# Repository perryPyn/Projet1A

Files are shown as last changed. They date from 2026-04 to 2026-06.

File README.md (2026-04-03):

Ce projet, réalisé dans le cadre du Semestre 6 à l'ENSEA (Année 2025-2026), consiste à développer un prototype de mesure de distance basé sur la technologie Time Of Flight (TOF). L'objectif est d'utiliser un capteur laser compact pour détecter des obstacles et commander une interface visuelle de retour.

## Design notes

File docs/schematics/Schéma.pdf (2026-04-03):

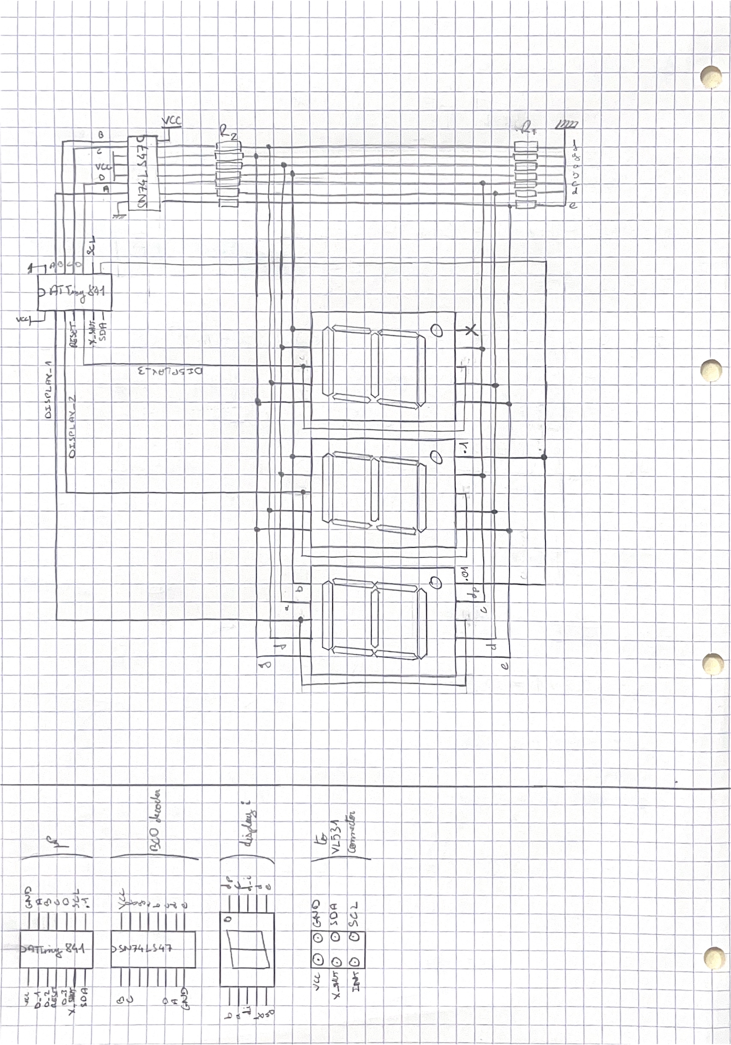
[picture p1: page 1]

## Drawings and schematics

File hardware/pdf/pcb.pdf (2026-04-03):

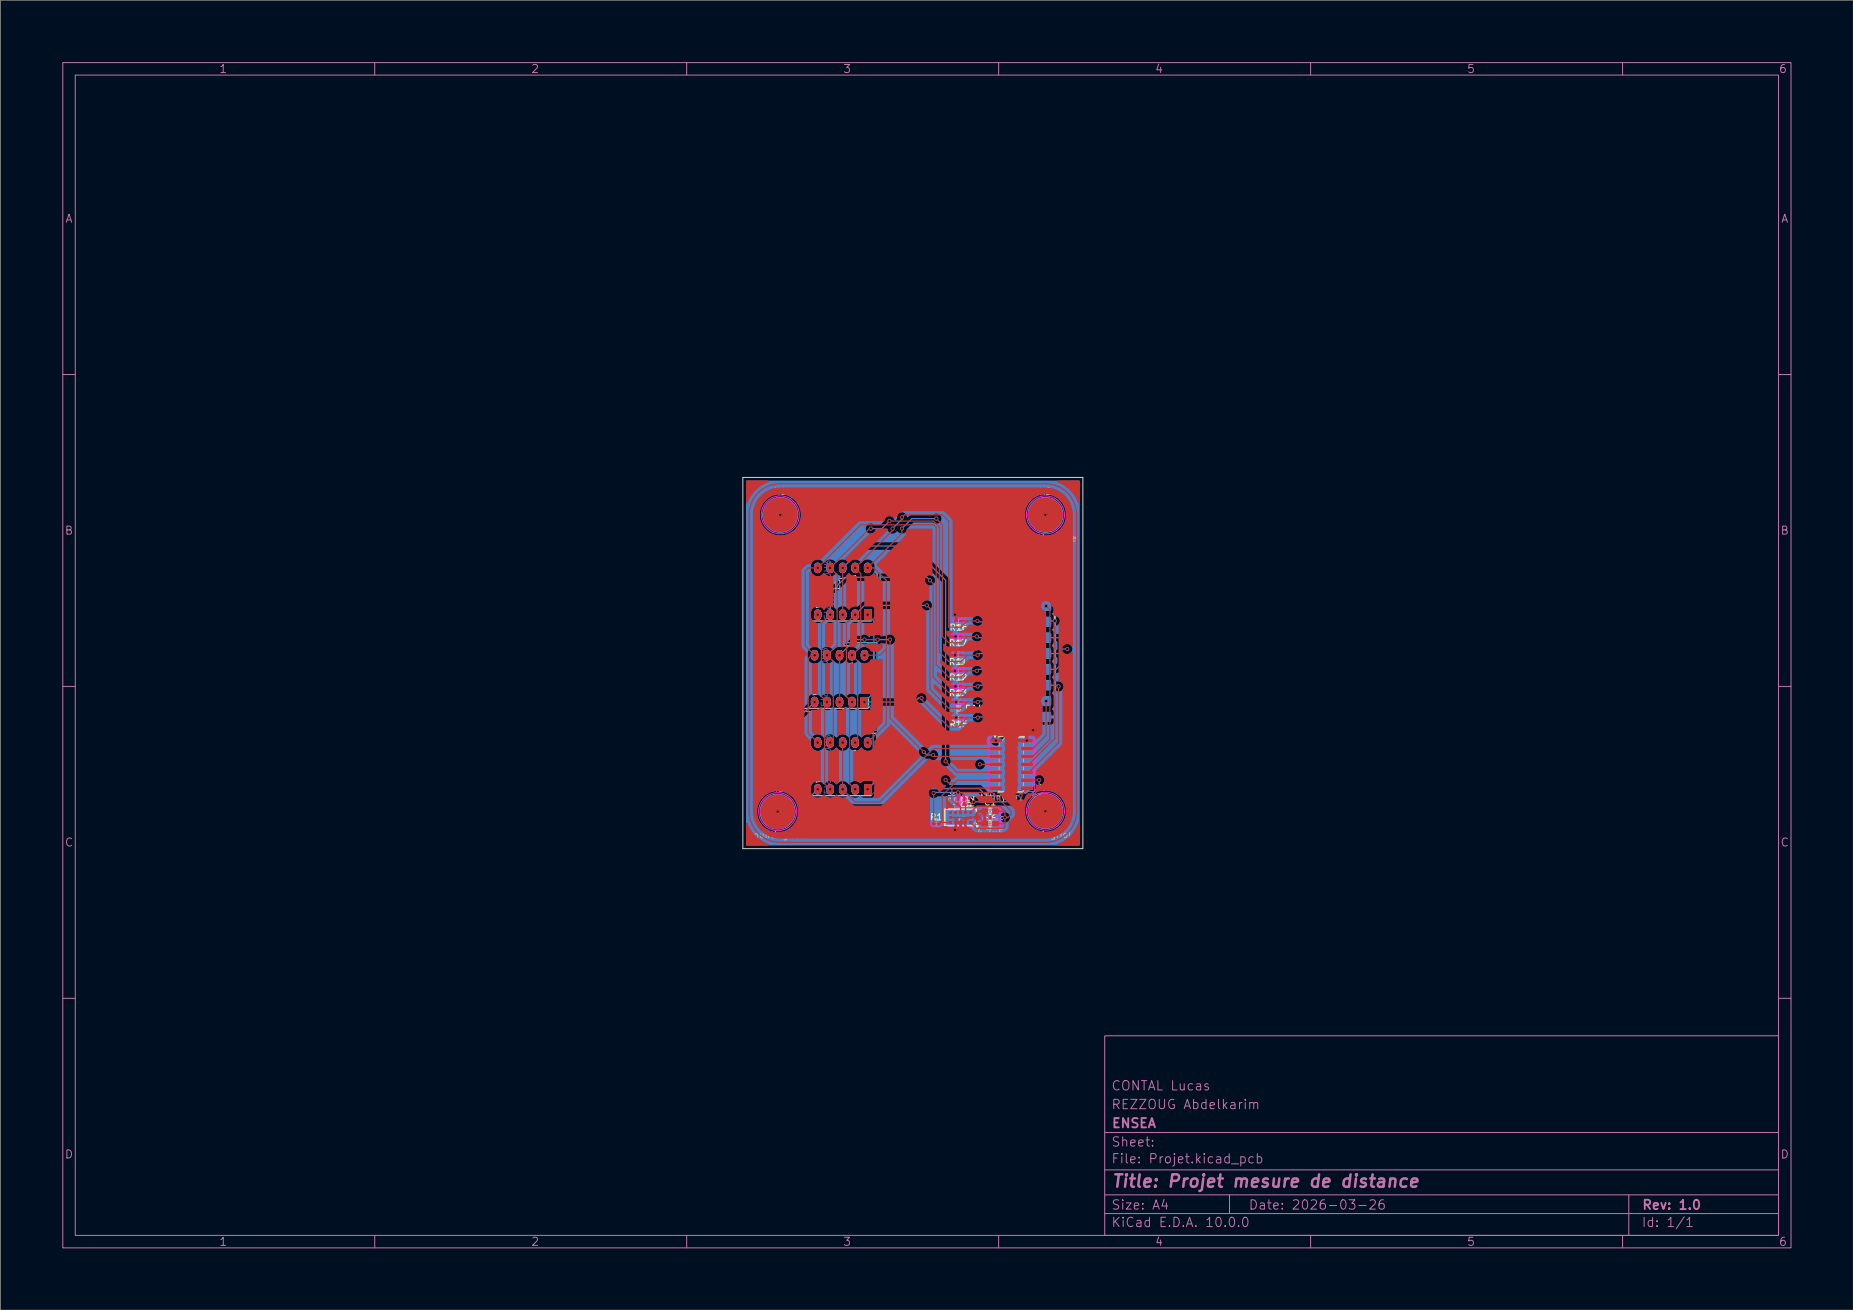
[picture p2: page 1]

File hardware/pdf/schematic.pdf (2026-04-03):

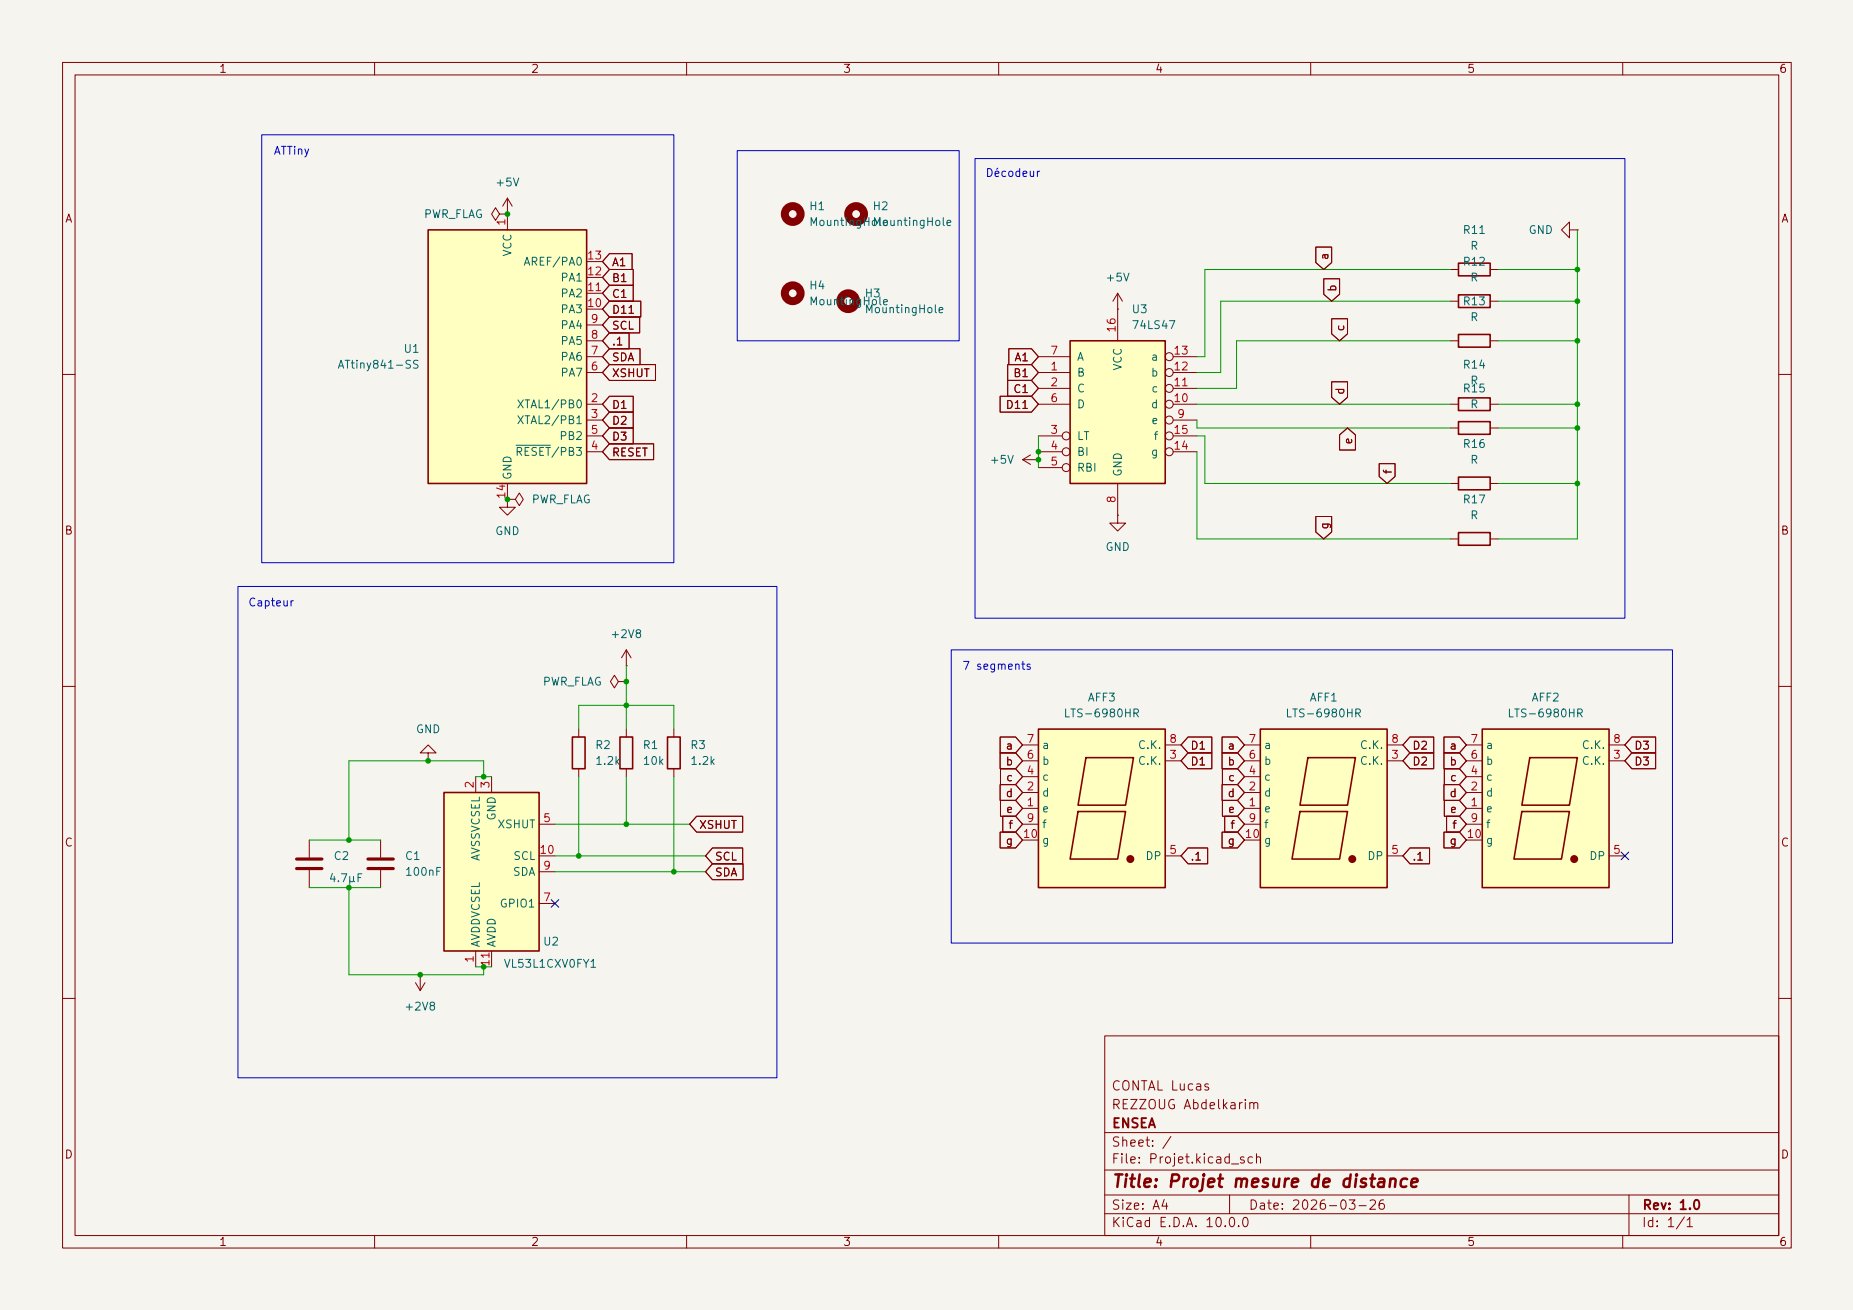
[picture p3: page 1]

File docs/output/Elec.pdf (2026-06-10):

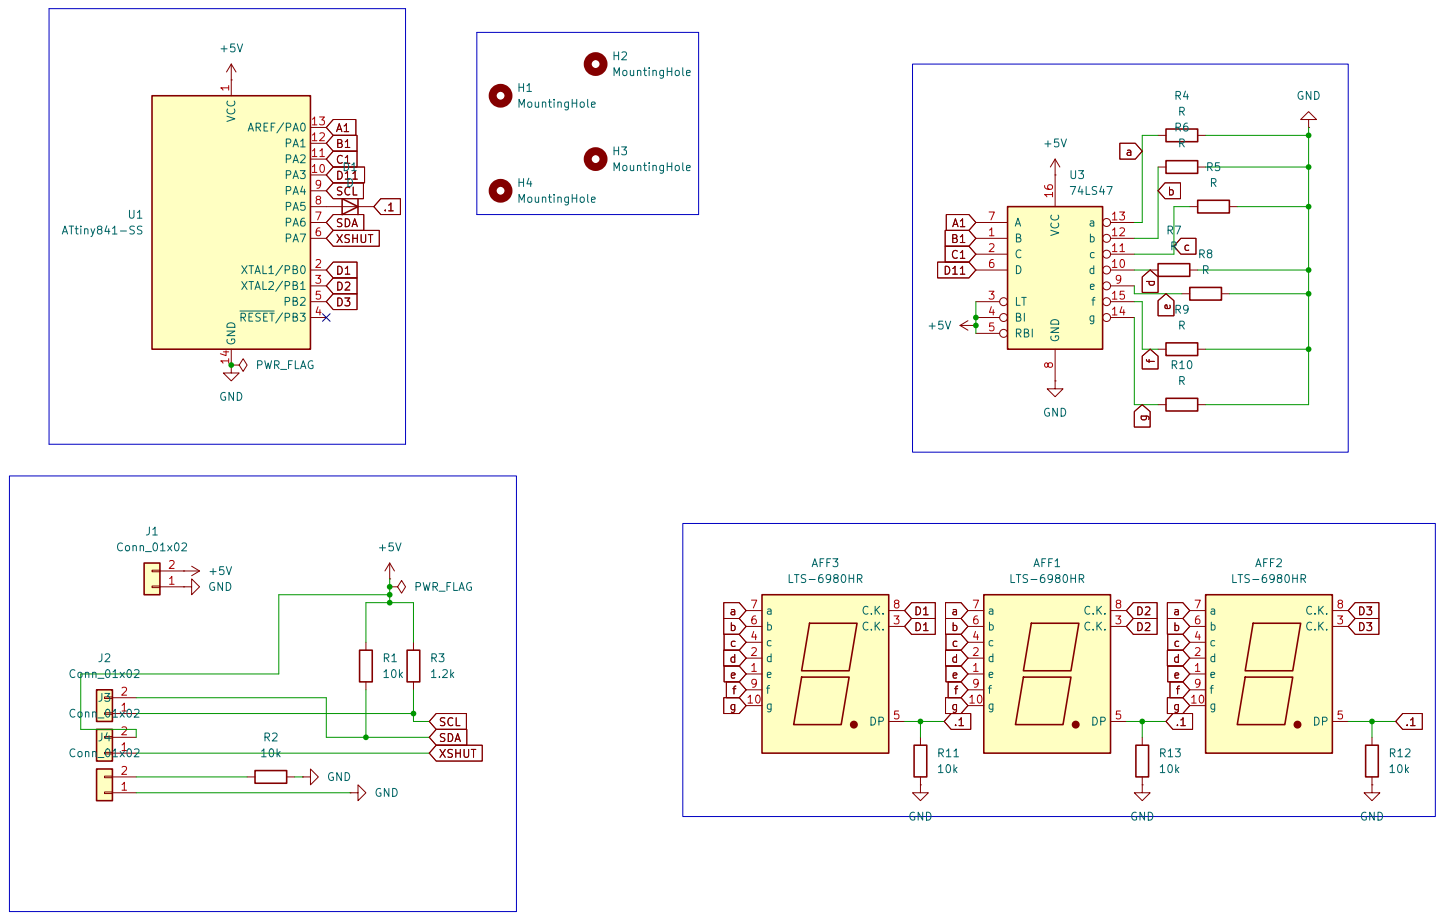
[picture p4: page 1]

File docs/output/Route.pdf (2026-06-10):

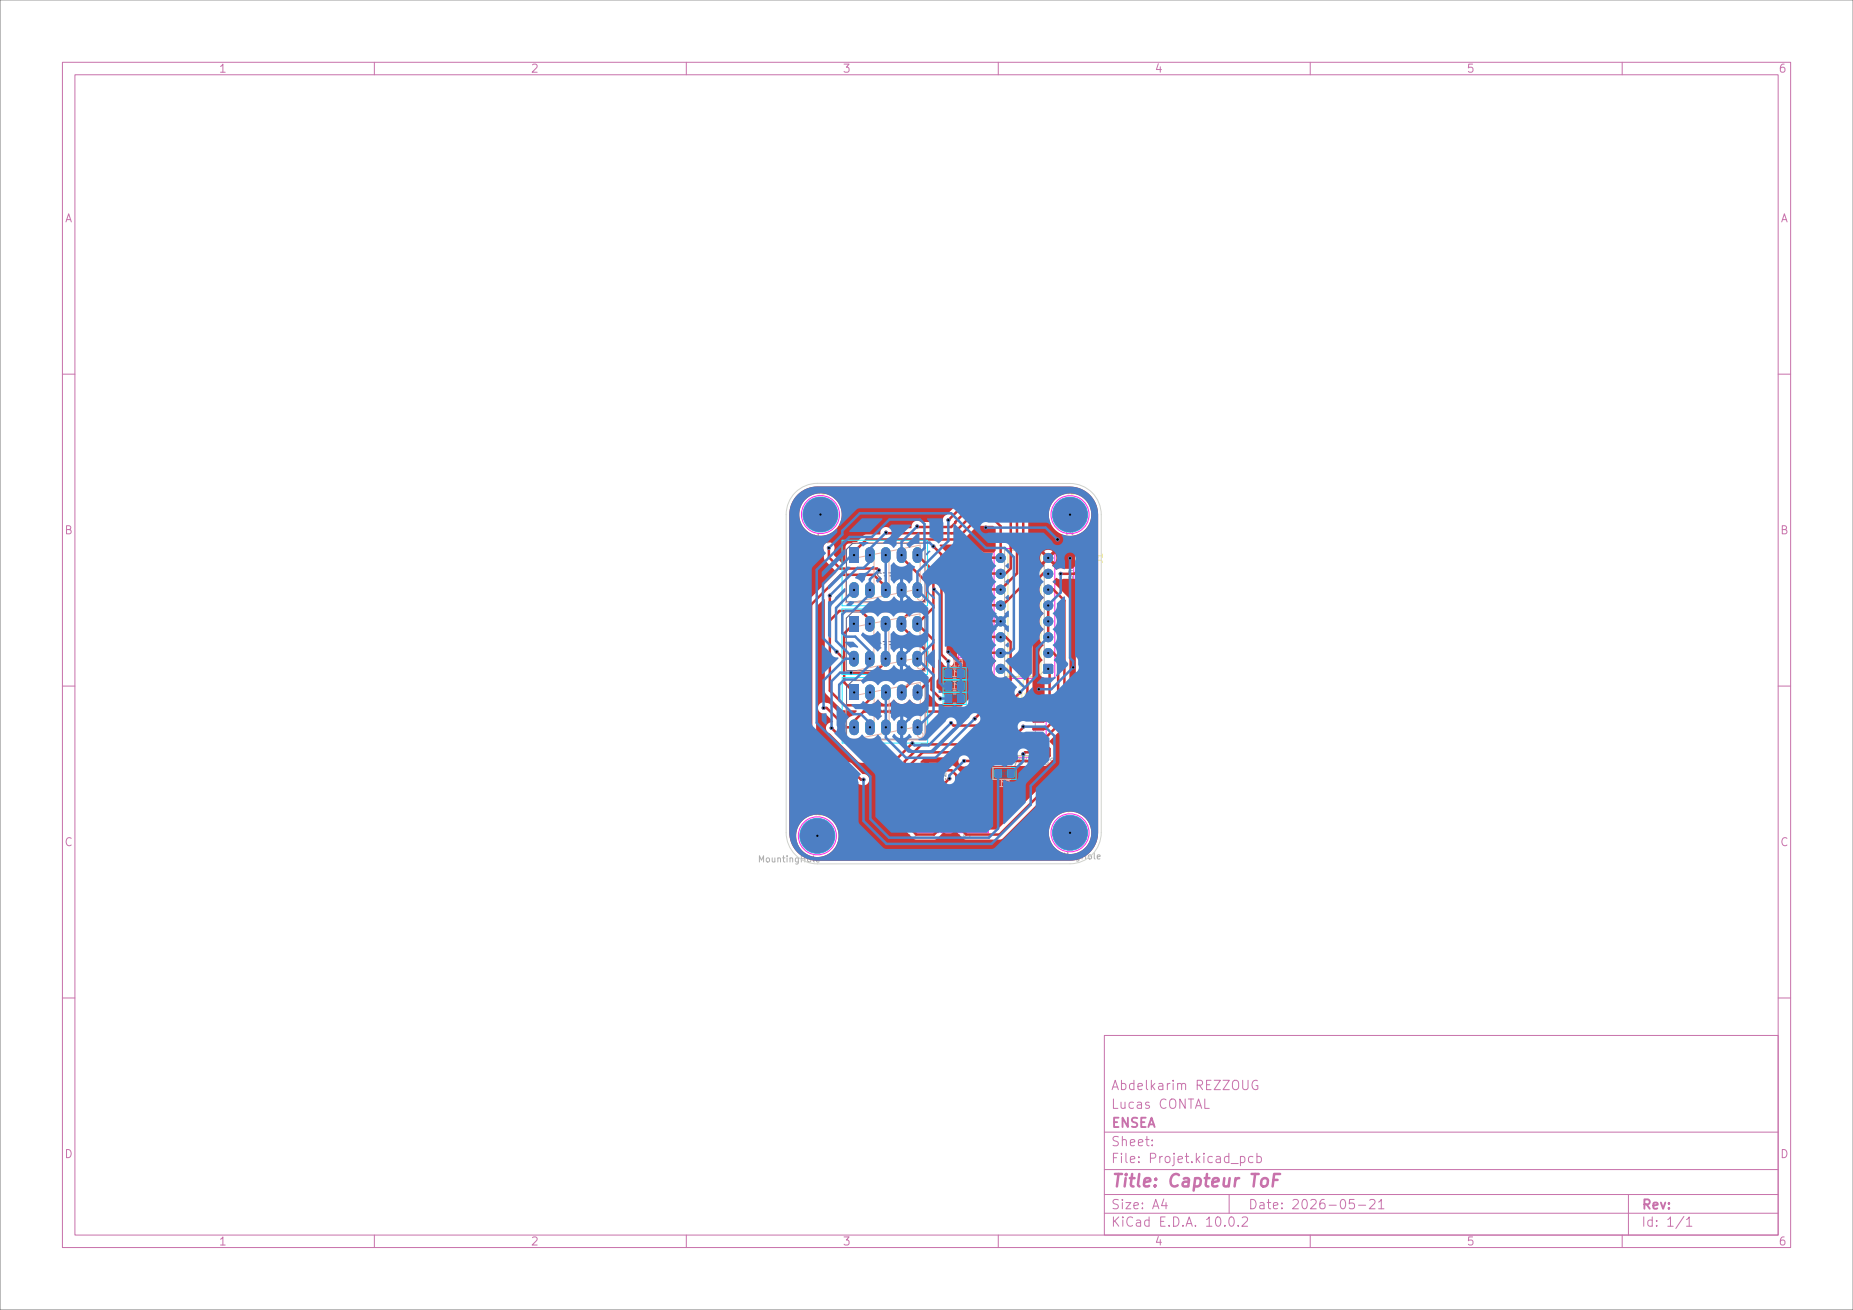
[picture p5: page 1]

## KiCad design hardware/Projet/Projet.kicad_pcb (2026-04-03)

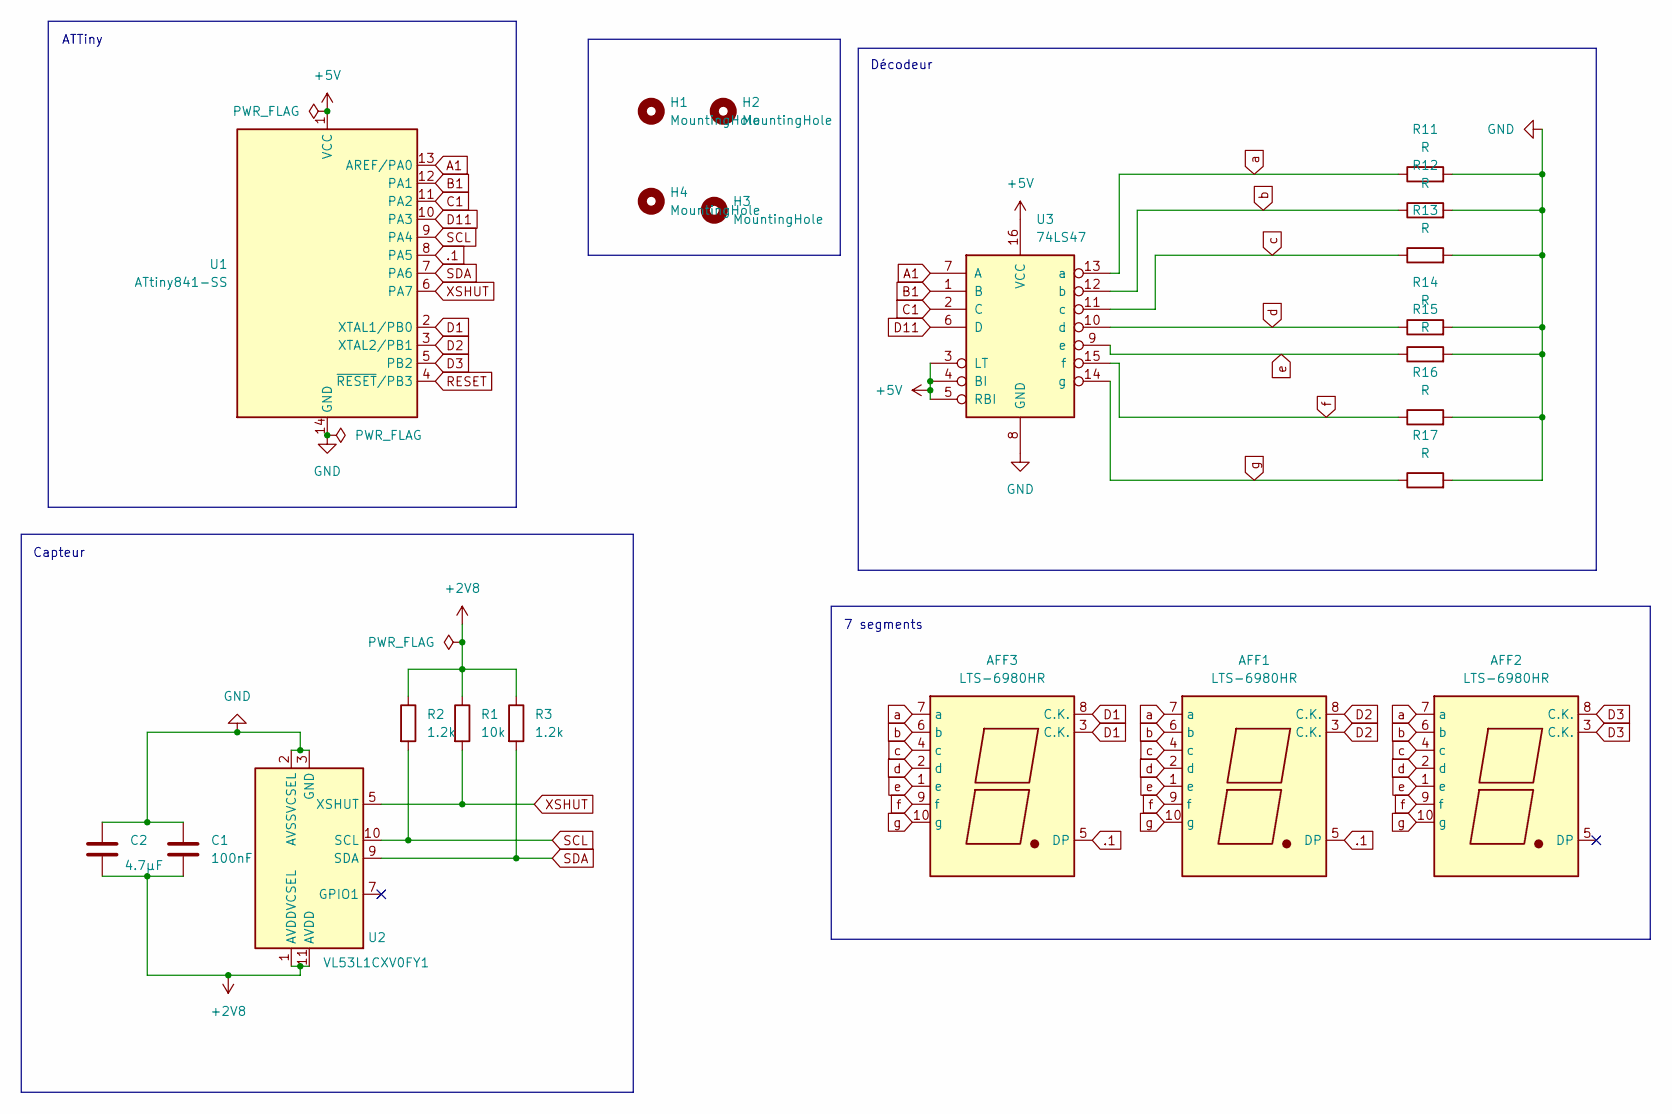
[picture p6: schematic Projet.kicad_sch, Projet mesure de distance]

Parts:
AFF1, AFF2, AFF3: LTS-6980HR; Sans titre_1
C1: 100nF; C_0603_1608Metric_Pad1.08x0.95mm_HandSolder
C2: 4.7µF; C_0603_1608Metric_Pad1.08x0.95mm_HandSolder
H1, H2, H3, H4: MountingHole; MountingHole_3.2mm_M3_DIN965_Pad
R1: 10k; R_0201_0603Metric_Pad0.64x0.40mm_HandSolder
R2, R3: 1.2k; R_0201_0603Metric_Pad0.64x0.40mm_HandSolder
R11, R12, R13, R14, R15, R16, R17: R; R_0201_0603Metric_Pad0.64x0.40mm_HandSolder
U1: ATtiny841-SS; SOIC-14_3.9x8.7mm_P1.27mm
U2: VL53L1CXV0FY1; ST_VL53L1x
U3: 74LS47; DIP-16_W7.62mm_SMDSocket_SmallPads

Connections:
+2V8: C1.2, C2.2, R1.1, R2.1, R3.1, U2.1 (AVDDVCSEL), U2.11 (AVDD)
+5V: U1.1 (VCC), U3.3 (LT), U3.4 (BI), U3.5 (RBI), U3.16 (VCC)
.1: AFF1.5 (DP), AFF3.5 (DP), U1.8 (PA5)
A1: U1.13 (AREF/PA0), U3.7 (A)
B1: U1.12 (PA1), U3.1 (B)
C1: U1.11 (PA2), U3.2 (C)
D1: AFF3.3 (C.K.), AFF3.8 (C.K.), U1.2 (XTAL1/PB0)
D2: AFF1.3 (C.K.), AFF1.8 (C.K.), U1.3 (XTAL2/PB1)
D3: AFF2.3 (C.K.), AFF2.8 (C.K.), U1.5 (PB2)
D11: U1.10 (PA3), U3.6 (D)
GND: C1.1, C2.1, R11.2, R12.2, R13.2, R14.2, R15.2, R16.2, R17.2, U1.14 (GND), U2.2 (AVSSVCSEL), U2.3 (GND), U2.4 (GND), U2.6 (GND), U2.12 (GND), U3.8 (GND)
RESET: U1.4 (~RESET/PB3)
SCL: R2.2, U1.9 (PA4), U2.10 (SCL)
SDA: R3.2, U1.7 (PA6), U2.9 (SDA)
XSHUT: R1.2, U1.6 (PA7), U2.5 (XSHUT)
a: AFF1.7 (a), AFF2.7 (a), AFF3.7 (a), R11.1, U3.13 (a)
b: AFF1.6 (b), AFF2.6 (b), AFF3.6 (b), R12.1, U3.12 (b)
c: AFF1.4 (c), AFF2.4 (c), AFF3.4 (c), R13.1, U3.11 (c)
d: AFF1.2 (d), AFF2.2 (d), AFF3.2 (d), R14.1, U3.10 (d)
e: AFF1.1 (e), AFF2.1 (e), AFF3.1 (e), R15.1, U3.9 (e)
f: AFF1.9 (f), AFF2.9 (f), AFF3.9 (f), R16.1, U3.15 (f)
g: AFF1.10 (g), AFF2.10 (g), AFF3.10 (g), R17.1, U3.14 (g)

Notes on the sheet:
Capteur
ATTiny
7 segments
Décodeur

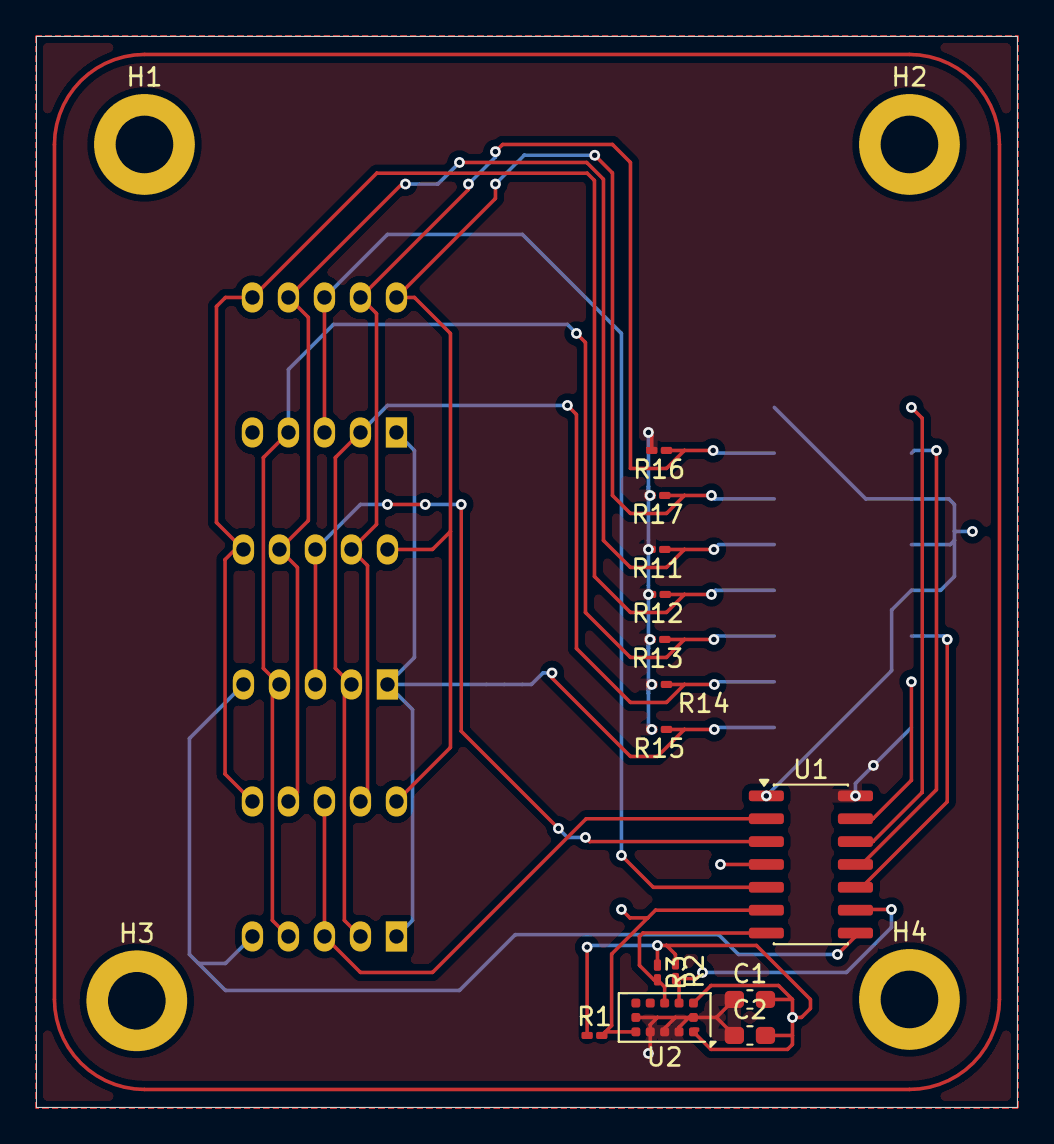
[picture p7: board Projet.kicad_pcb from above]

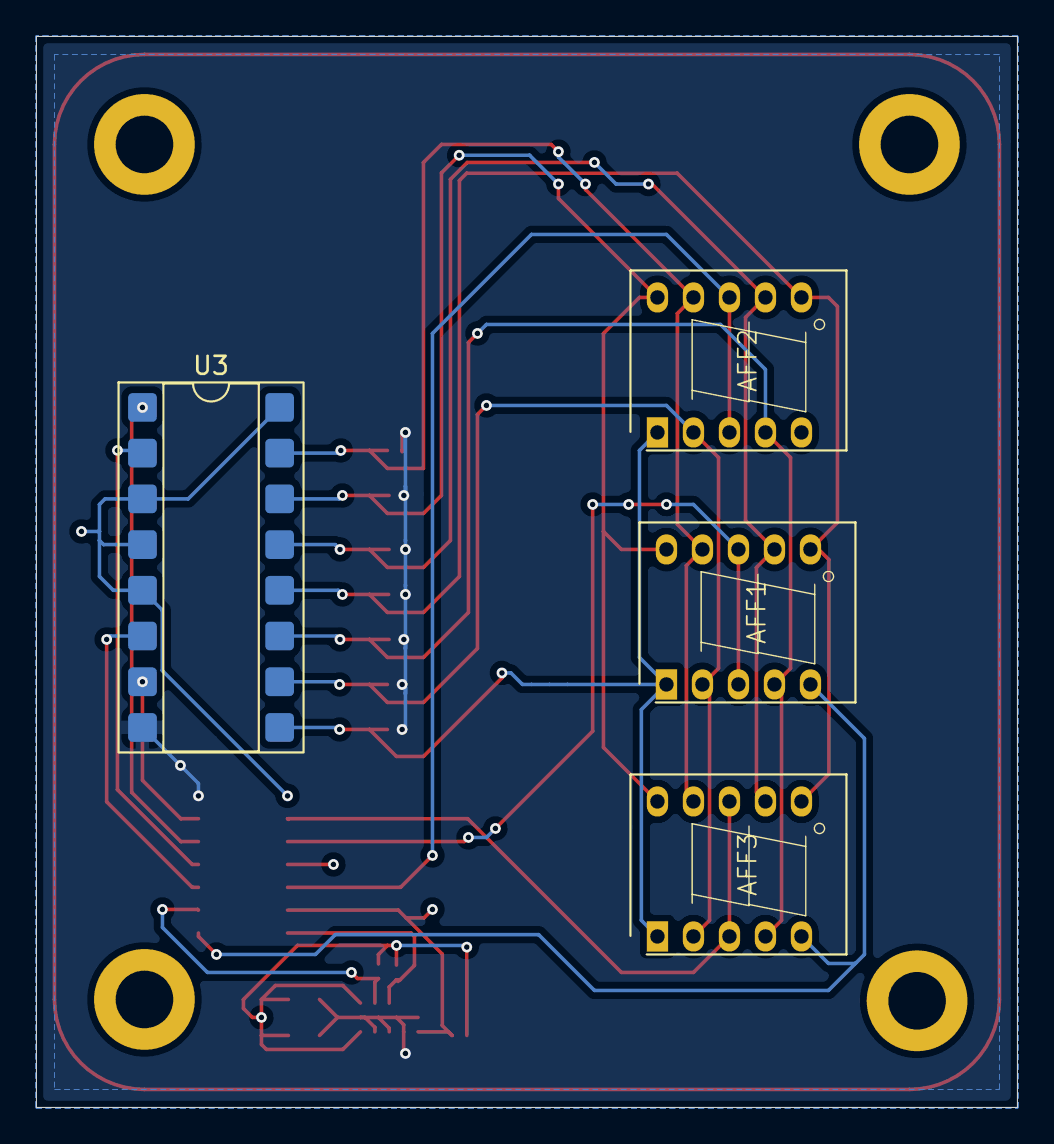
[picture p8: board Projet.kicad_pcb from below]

Board: 2 copper layers, 54.5 x 59.5 mm, 22 parts (4 on the bottom side), 21 nets.

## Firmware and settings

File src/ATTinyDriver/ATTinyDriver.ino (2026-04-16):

// #include "display.h"
#include "gpio.h"
#include "utils.h"
#include "capteur.h"

/*

PORTA : I2C(4,6), BIT(0,1,2,3), DIXIEME(5), CENTIEME(7)
PORTB : DISPLAY(0,1,2), RESET(3)

*/



void setup() {

  PIN_Configure();

  Capteur_Configure();

  Timer_Configure();
}



void loop() {

  Capteur_Read();
  FormatNumber(numberToDisplay, &digit_1, &digit_2, &digit_3);
}

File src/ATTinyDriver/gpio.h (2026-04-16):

#ifndef GPIO_H
#define GPIO_H

#include <avr/io.h>
#include <avr/interrupt.h>
#include "display.h"

/*
Schéma de configuration des pins de l'ATTiny841 :

                           ATTiny841
                        +------U------+
                  VCC  1|             |14  GND
     (DISPLAY_1)  PB0  2|             |13  PA0  (BIT_0)
     (DISPLAY_2)  PB1  3|             |12  PA1  (BIT_1)
         (RESET)  PB3  4|             |11  PA2  (BIT_2)
     (DISPLAY_3)  PB2  5|             |10  PA3  (BIT_3)
              ()  PA7  6|             |9   PA4  (I2C_SCL)
       (I2C_SDA)  PA6  7|             |8   PA5  (DECIMAL)
                        +-------------+

*/

/* --- Pins liason I2C --- */
#define I2C_SCL PA4 // Clock
#define I2C_SDA PA6 // Data

/* --- Pins pour I/O les display 7-segments --- */
#define DISPLAY_1 PB0
#define DISPLAY_2 PB1
#define DISPLAY_3 PB2

/* --- Pins pour le décodeur --- */
#define BIT_0 PA0
#define BIT_1 PA1
#define BIT_2 PA2
#define BIT_3 PA3

/* --- Pins pour les décimales des afficheurs --- */
#define DIXIEME  PA5
#define CENTIEME PA7



/* === Prototypage des fonctions === */
#ifdef __cplusplus
extern "C" {
#endif

extern volatile uint16_t numberToDisplay;
extern volatile uint8_t decimalPoint;
extern volatile uint8_t digit_1;
extern volatile uint8_t digit_2;
extern volatile uint8_t digit_3;

void PIN_Configure(void);
void PIN_Driver(volatile uint8_t *port, uint8_t pin, uint8_t state);

void Timer_Configure(void);

void setNumberToDisplay(uint16_t n);

#ifdef __cplusplus
}
#endif

#endif

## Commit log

2026-04-03 Initial commit: Ouverture du git
    [Projet.kicad_pcb, Projet.kicad_sch]
2026-04-03 maj driver attiny
2026-04-09 modifications driver, affiche le num du display
2026-04-09 modification de FormatNumber, fonctionne ok
2026-04-09 l'afficheur fonctionnent totalement, numberToDisplay sera la variable a modifier par la lecture du capteur
2026-04-09 deplacement de FormatNumber() dans le loop pour ne pas gener l'affichage
2026-04-13 ajout reset liason I2C en cas de crash
    [ATTinyDriver.ino, gpio.h]
2026-04-13 init depuis la branch capteur
2026-04-15 code pour enlever les 0 inutiles ok, manque le dp
